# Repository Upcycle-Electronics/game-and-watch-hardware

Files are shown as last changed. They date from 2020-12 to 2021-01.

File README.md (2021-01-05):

# game-and-watch-hardware
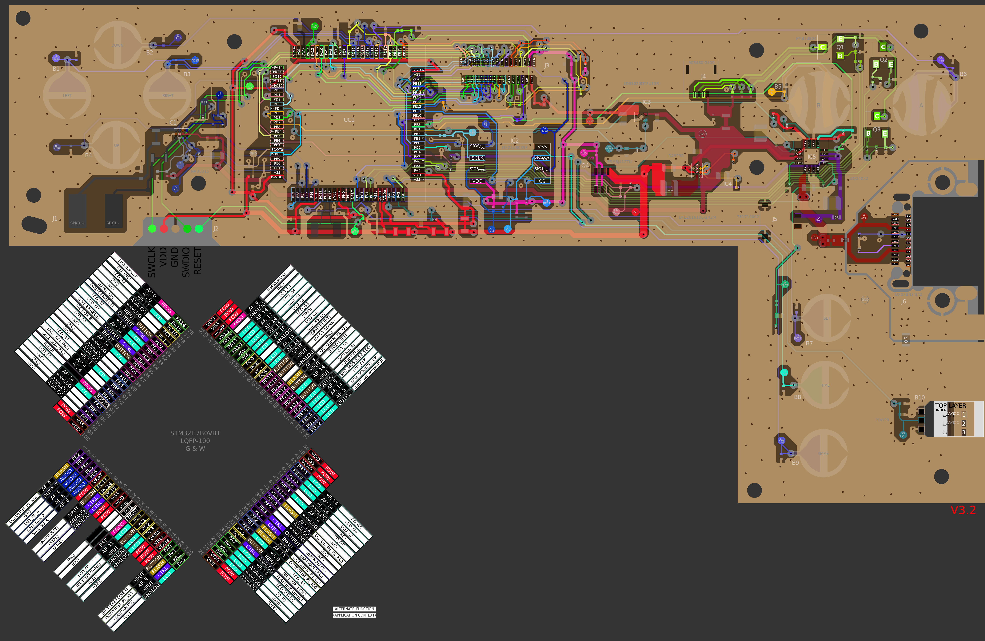
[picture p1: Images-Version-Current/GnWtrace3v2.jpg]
Version 3.2


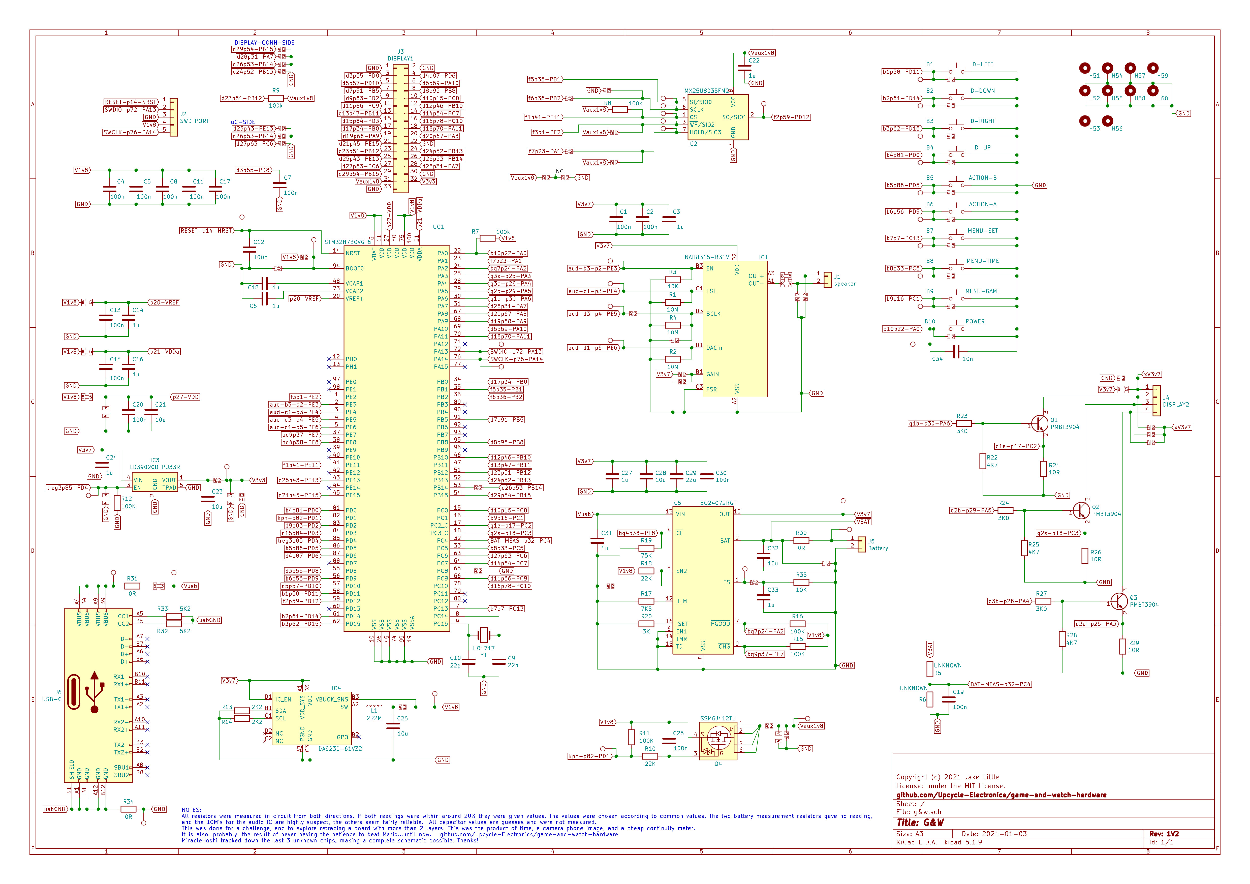
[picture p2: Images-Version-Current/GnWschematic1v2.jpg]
Version 1.2


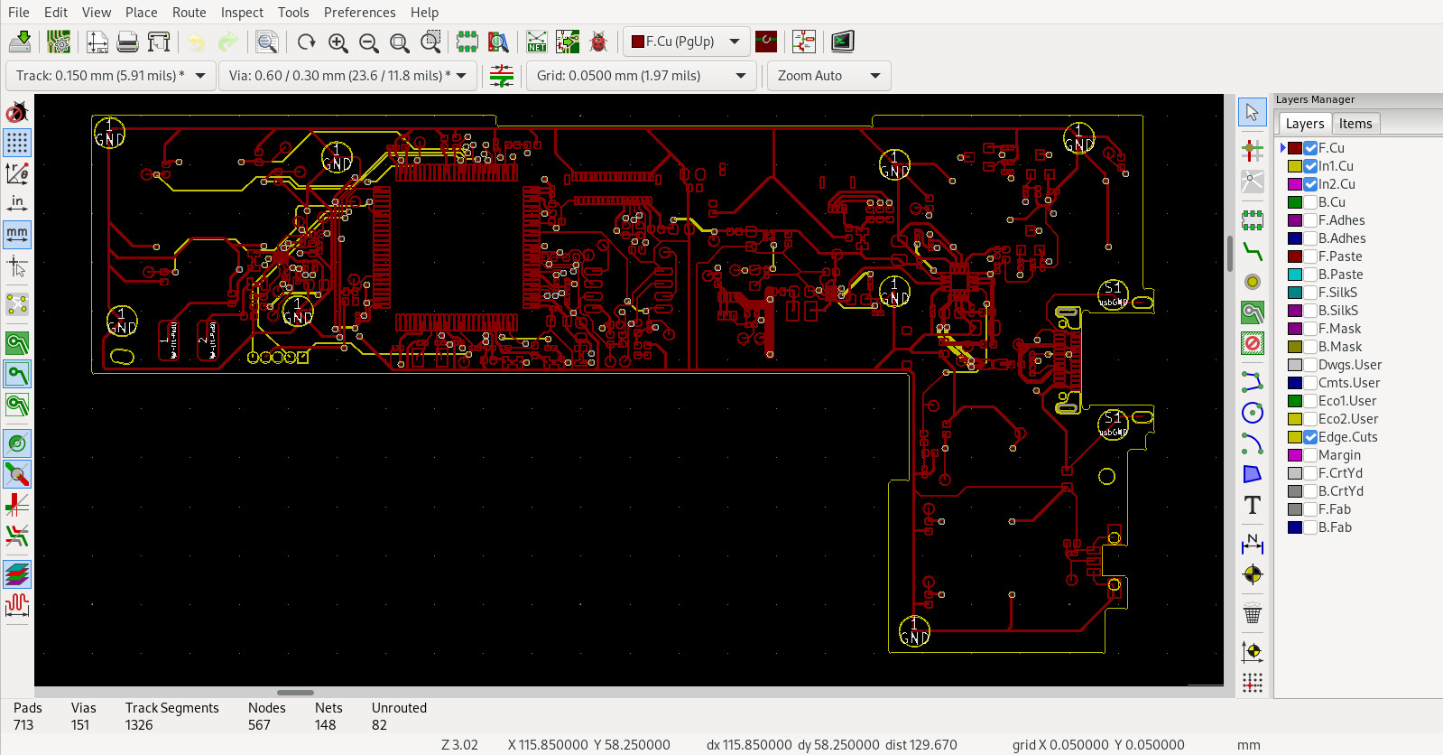
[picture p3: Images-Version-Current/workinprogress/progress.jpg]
progress


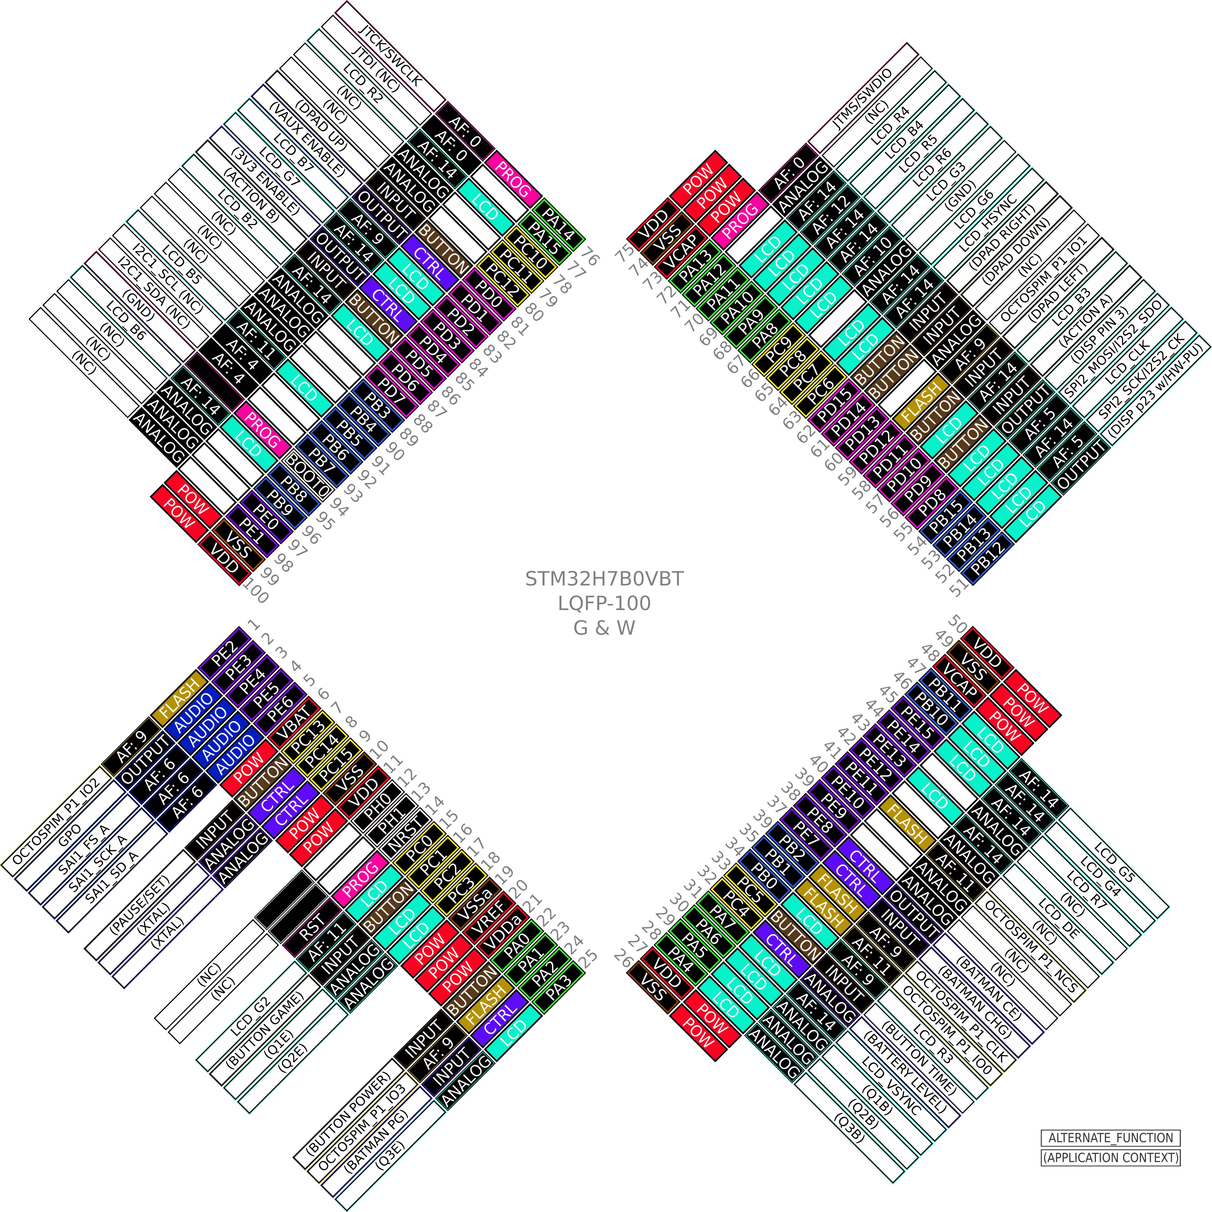
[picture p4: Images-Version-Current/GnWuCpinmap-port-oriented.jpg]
PinMap


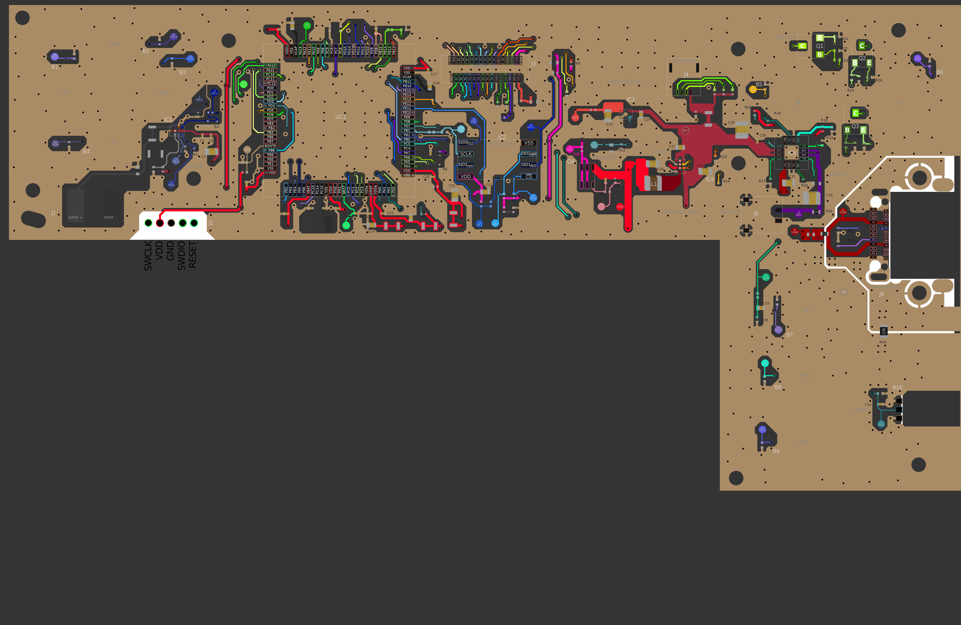
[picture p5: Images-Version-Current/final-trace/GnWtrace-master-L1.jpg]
Layer 1


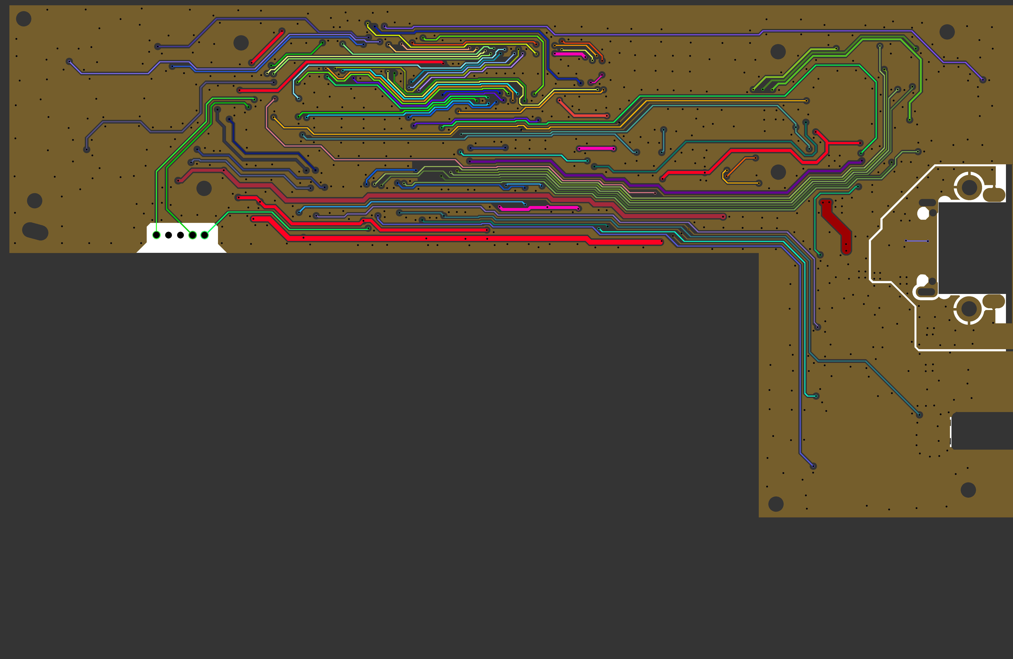
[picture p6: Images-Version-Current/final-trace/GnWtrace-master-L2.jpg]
Layer 2


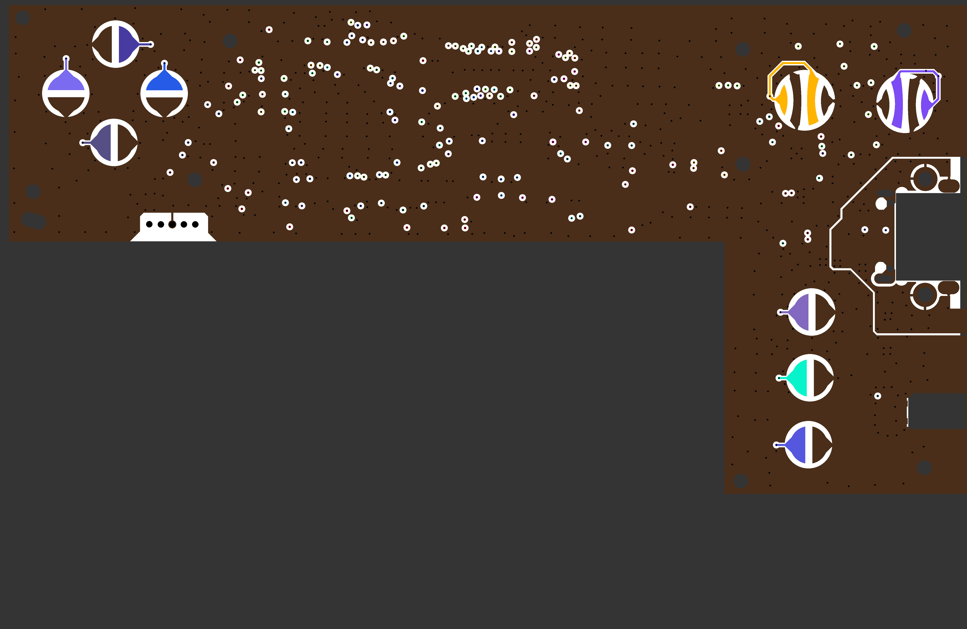
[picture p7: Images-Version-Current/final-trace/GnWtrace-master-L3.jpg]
Layer 3


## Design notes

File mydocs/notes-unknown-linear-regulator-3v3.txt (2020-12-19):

3V3 REGULATOR
IS NOT:
XC6220           no footprint match
XC6221           no footprint match
XC6222           no footprint match
XC6223           device marks do not match
XC6224           no footprint match
XC6225           no footprint match
XC6229           no footprint match
TLV707335DQN     device marks do not match F6
TLV70733DQNR     device marks do not match YH
TLV70733DQNR1    device marks do not match BN
TLV70733DQNT     device marks do not match YH
TLV70733PDQN     device marks do not match TI
TLV71733PDQN     device marks do not match VG
TLV73333PDQN     device marks do not match FM
TLV74233PDQN     device marks do not match 7Z
TLV75533PDQN     device marks do not match AN
LP5907SNX-3.3    device marks do not match CN
TPS7A0533PDQN    device marks do not match CD
TPS7A0333DQN     device marks do not match IH
TPS7A0333PDQN    device marks do not match G5
TPS7A0233DQN     device marks do not match IF
TPS7A0233PDQN    device marks do not match FA
LD6805K33P       device marks do not match 
RP202K           device marks may match but Ricoh does not spec marking or guarantee consistency

IS:
SIZE:
1mm x 1mm

FOOTPRINT COULD BE:
X2SON-4 1X1mm
DFN1010C-4
SOT1194-1
4-UDFN Exposed Pad
USPQ-4B03

PINOUT:
PIN 1 = output
PIN 2 = ground
PIN 3 = enable (active high)
PIN 4 = input

PARTNUMBER= maybe top line "M33" (M is underlined) ; is probably either "OH" or "0H" from the second line

----------------------------------------------------------------------------
DC TO DC CONVERTER:
IS: 
SIZE:
1.3mm x 1.8mm

FOOTPRINT COULD BE:
DSBGA-12

IS NOT:
listed on the TI website matching this package and marking codes
TPS62350YZGR device marks do not match TPS62350
TPS62352YZGR device marks do not match TPS62352
TPS62353YZG_ device marks do not match TPS62353
TPS62354YZGR device marks do not match TPS62354
TPS62356YZG_ device marks do not match TPS62356
 device marks do not match 
 device marks do not match 
 
MP28160 wrong size/wrong connections
BD83070 wrong size/wrong connections
MP5461 wrong size/wrong connections
MAX77503 wrong size/wrong connections

Almost Matching 12 ball footprints to ignore:
CSP-12      1.4mm x 1.8mm
UCSP50L1C   1.20mm × 1.60mm
W121A1+3    1.398mm +/-0.0025 x 1.848mm +/-0.0025

A=1 B=2 C=3
1A

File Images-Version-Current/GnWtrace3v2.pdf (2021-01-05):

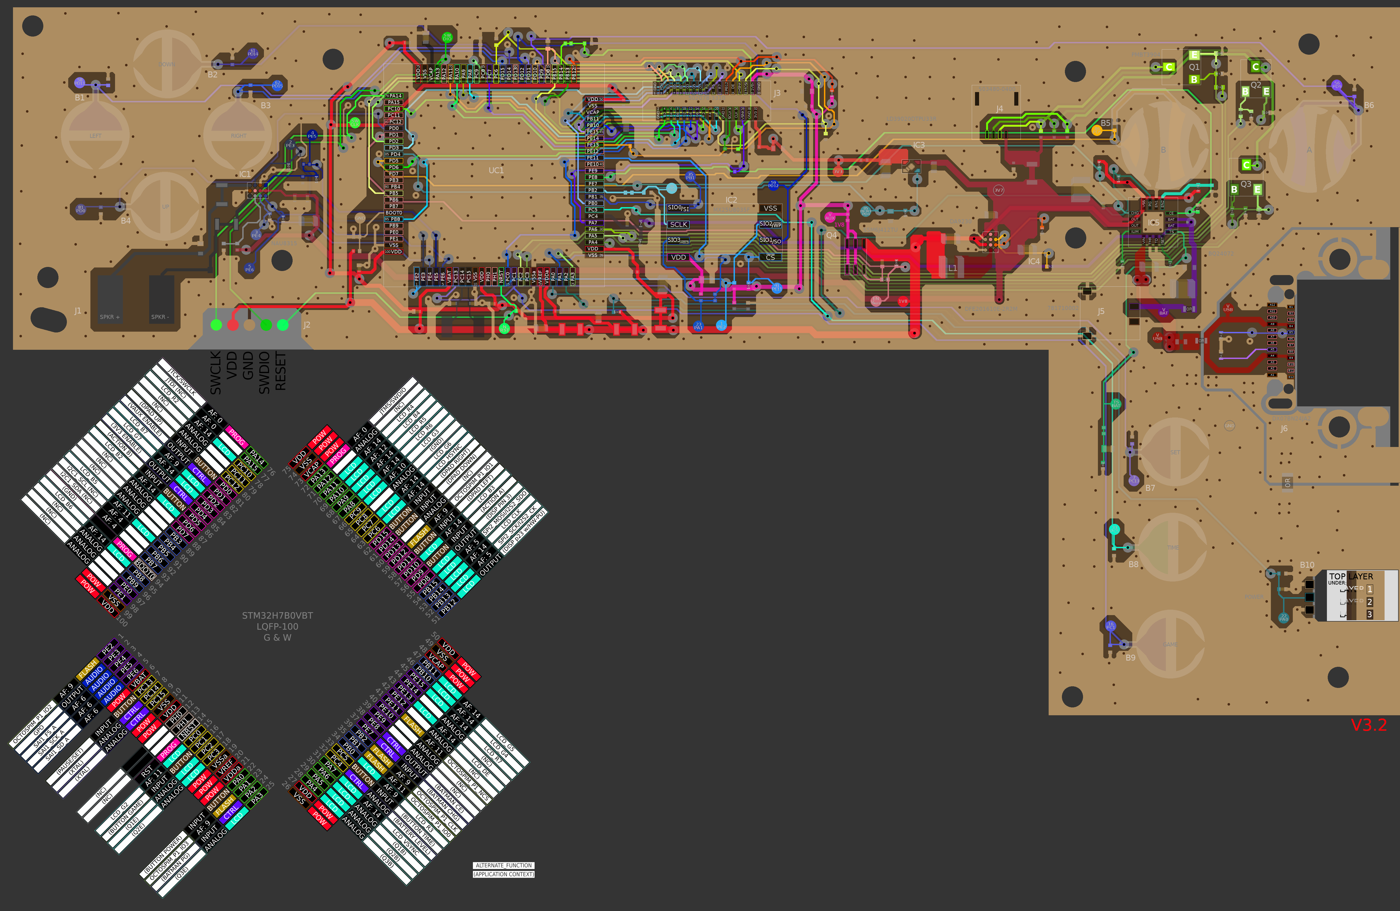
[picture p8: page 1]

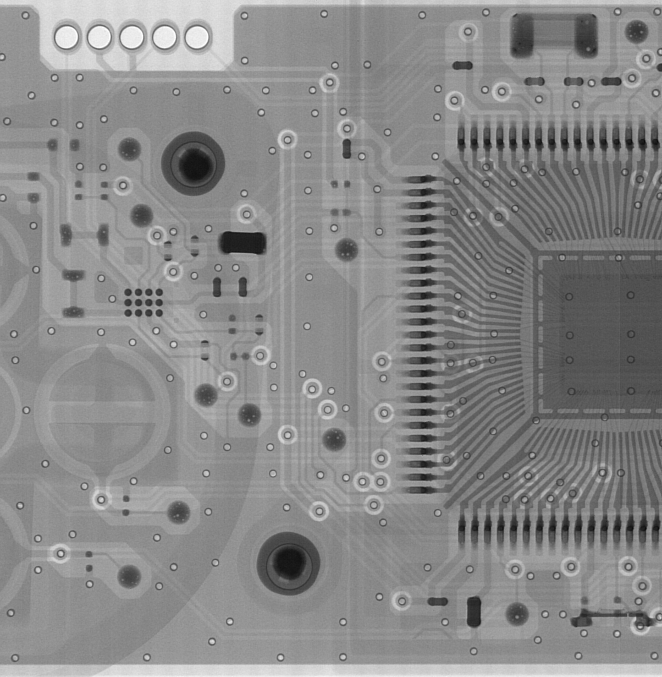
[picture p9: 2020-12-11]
gimp/board-pics/G&W CPU.jpg

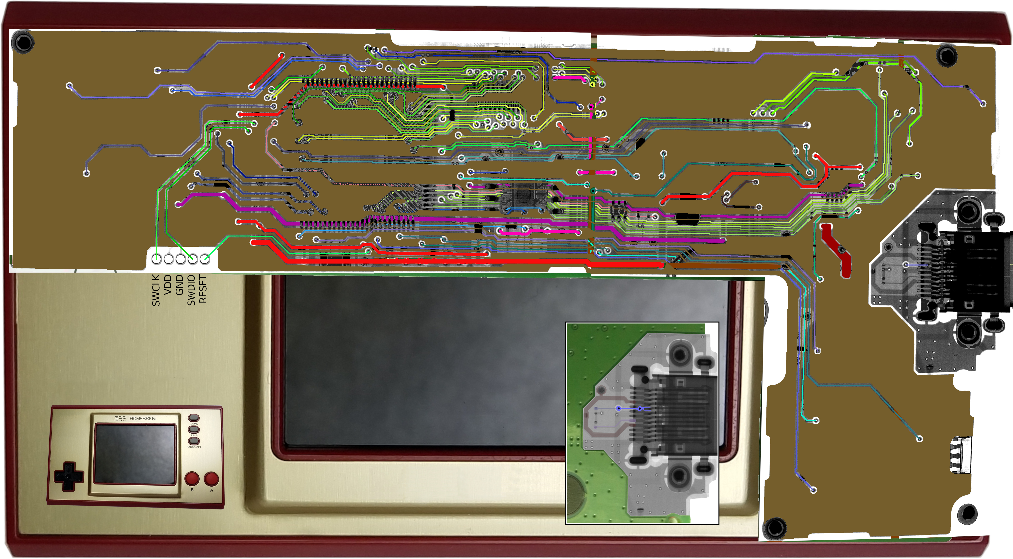
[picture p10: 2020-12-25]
gimp/board-pics/innerlayertraces.jpg

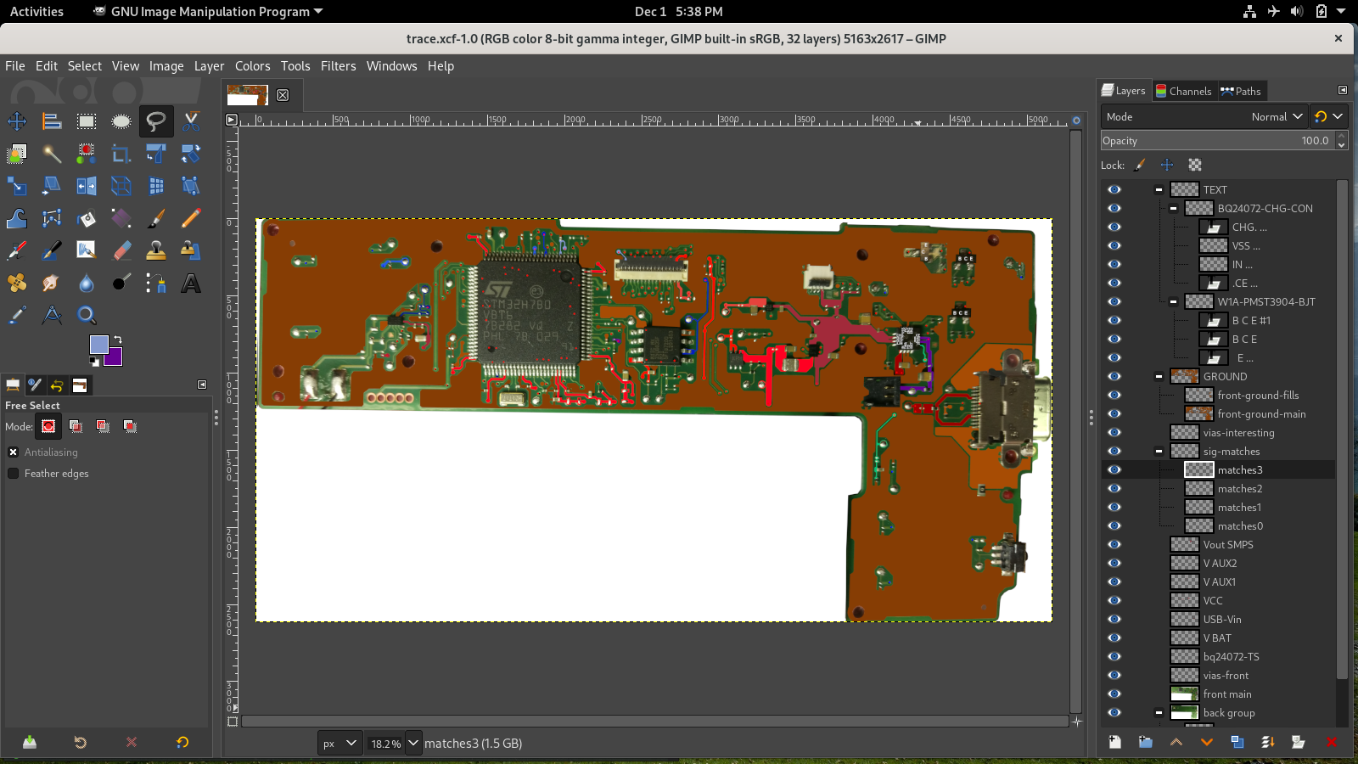
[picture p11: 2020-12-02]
gimp/board-pics/progress.png

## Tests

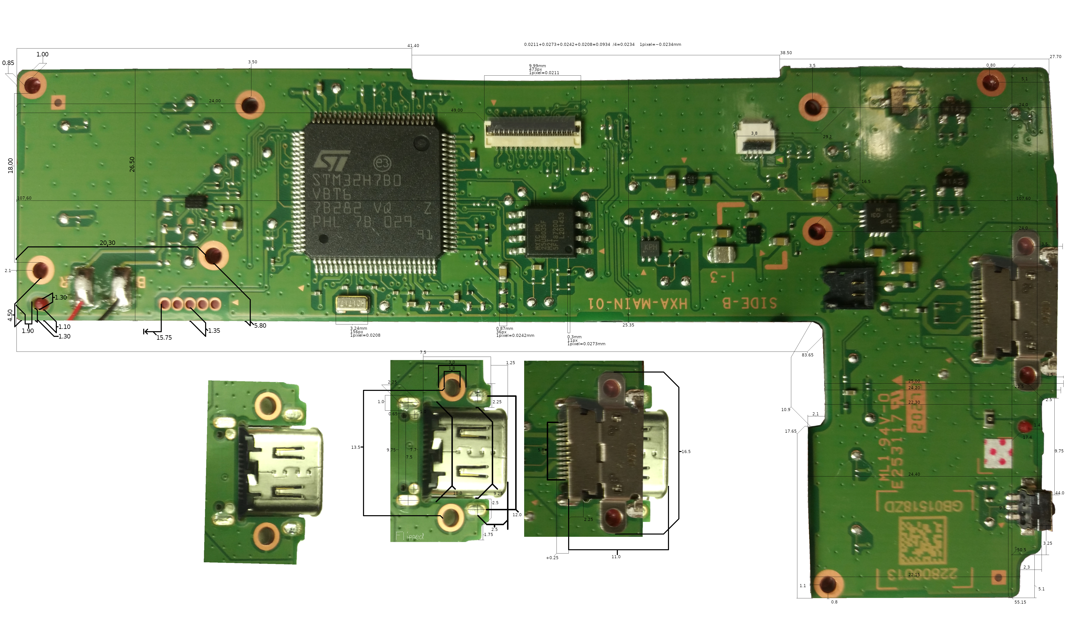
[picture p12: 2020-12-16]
Images-Version-Current/workinprogress/GnWtracemeasureWIP.jpg

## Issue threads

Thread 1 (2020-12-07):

Correction on regulator trace.

joksan, 2020-12-07:
Hello!

First of all, thank you for this amazing effort of reverse engineering the Game And Watch. It's been incredibly useful to me and I'm sure to others as well.

I just wanted to kindly point out an error I discovered in the colored trace images (GnWtrace1v0.png and others). In the 1.8V regulator area there's this SDM component that is an inductor in a 2016 package (it's right besides the M-1 label). Both ends of the inductor are colored the same, which suggests that they're joined together. I'm afraid those are different traces, as they show very different signals in an oscilloscope. This inductor is part of the buck converter circuit and has the output switch at the end that leads to the regulator IC and the actual power output going to the rest of the circuit at the other end.

I hope you find this little bit of information useful. Have a nice day!

Upcycle-Electronics, 2020-12-08:
I should have thought of that. Continuity isn't always continuity. I'll ty and push a change tomorrow.

  I guess this means that little stub of a trace on the left side of IC4 must be where the diode is hidden. Either that or I'm totally clueless about this switching topology. Both are equally possible. I really wish I could find out the chip used.
Thanks for letting me know.

Upcycle-Electronics, 2020-12-09:
I think I fixed it. Thanks again.
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

joksan, 2020-12-10:
Yay! thanks!

Closed 2020-12-09.

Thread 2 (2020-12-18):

I came to help.

miraclehoshi, 2020-12-18:
I noticed that you are not yet in Discord dealing with game and watch hacks.

Except for the power switch parts, all parts were found with the help of me and several people.

Type-C Connector : JAE DX07BN24JA2R1300
1.9V Reg : dialog semiconductor DA9230
3.3V Reg : STMicroelectronics LD39020DTPU33R
Audio Amplifier : nuvoton NAU8315

If you are interested, how about joining Discord?
https://discord.gg/P7uPM3Sy

Upcycle-Electronics, 2020-12-18:
Alright. I'll set up an account when I get back on a computer tomorrow. Thanks for the info.
Do you know the power button and crystal part number?
  Also, sources?
I searched:
smdmark.com (where I got the MOSFET pn from)
smd.yooneed.one
alltransistor.com
octopart
digikey, mouser, arrow, newark, ti, torex, lcsc, aliex
...so far. It seems you have sources and techniques I'd like to know and get familiar with.

miraclehoshi, 2020-12-18:
Crystal is a common standard, so I couldn't think of finding it. Let's try.
The sources of other parts were found by searching several sites. I was able to find it with various help.
I only used digikey and mouser.

The power switch part has been around for a long time on Nintendo, but I haven't been able to find the exact part yet. Considering that the genuine switch has not been found while at least three replica parts have been released in China, it may be a special ordered part from Nintendo.

Upcycle-Electronics, 2020-12-19:
Thanks for the help and info. Discord is not a good fit for me. Tracking down everything they are doing in the background is too much of a side project for a dumb guy like myself. Let me know if you guys move to something open source and privacy aware. I prefer a written messaging system anyways

  I wish the DA9230 wasn't made of unobtainium. That was the most interesting chip in the whole device. At least the pull down resistors to disable the I2C lines finally make sense.
If you read the documentation for the 9230 demo board they list a Murata inductor that is probably the one used on the GnW. At least it's the right odd footprint.

Upcycle-Electronics, 2020-12-20:
Thanks again. The schematic has been updated.

Closed 2020-12-20.

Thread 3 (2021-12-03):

STM32H7B0V(B|G?)T6

martaaay, 2021-12-03:
My apologies - I'm not familiar with the ST2 line, but I couldn't find STM32H7B0V**G**T6, but I did find STM32H7B0V**B**T6:
[linky](https://www.st.com/content/st_com/en/products/microcontrollers-microprocessors/stm32-32-bit-arm-cortex-mcus/stm32-high-performance-mcus/stm32h7-series/stm32h7b0-valu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
)
Just wondering if this is a typo.

Upcycle-Electronics, 2021-12-04:
Indeed it is a typo. QWERTY strikes again. I'm not fixing it ATM though. I'm too far removed from this project to sort it out and edit for a typo. I'm 4 months into buring out on my first large 3d printing project worth sharing and doing post design documentation. My brain is 180 degrees away from KiCAD right now. Hopefully my error didn't cost you too mach wasted time.
https://github.com/Upcycle-Electronics/game-and-watch-hardware/blob/main/gimp/board-pics/front1.jpg

martaaay, 2021-12-30:
Noooo worries. No time lost!

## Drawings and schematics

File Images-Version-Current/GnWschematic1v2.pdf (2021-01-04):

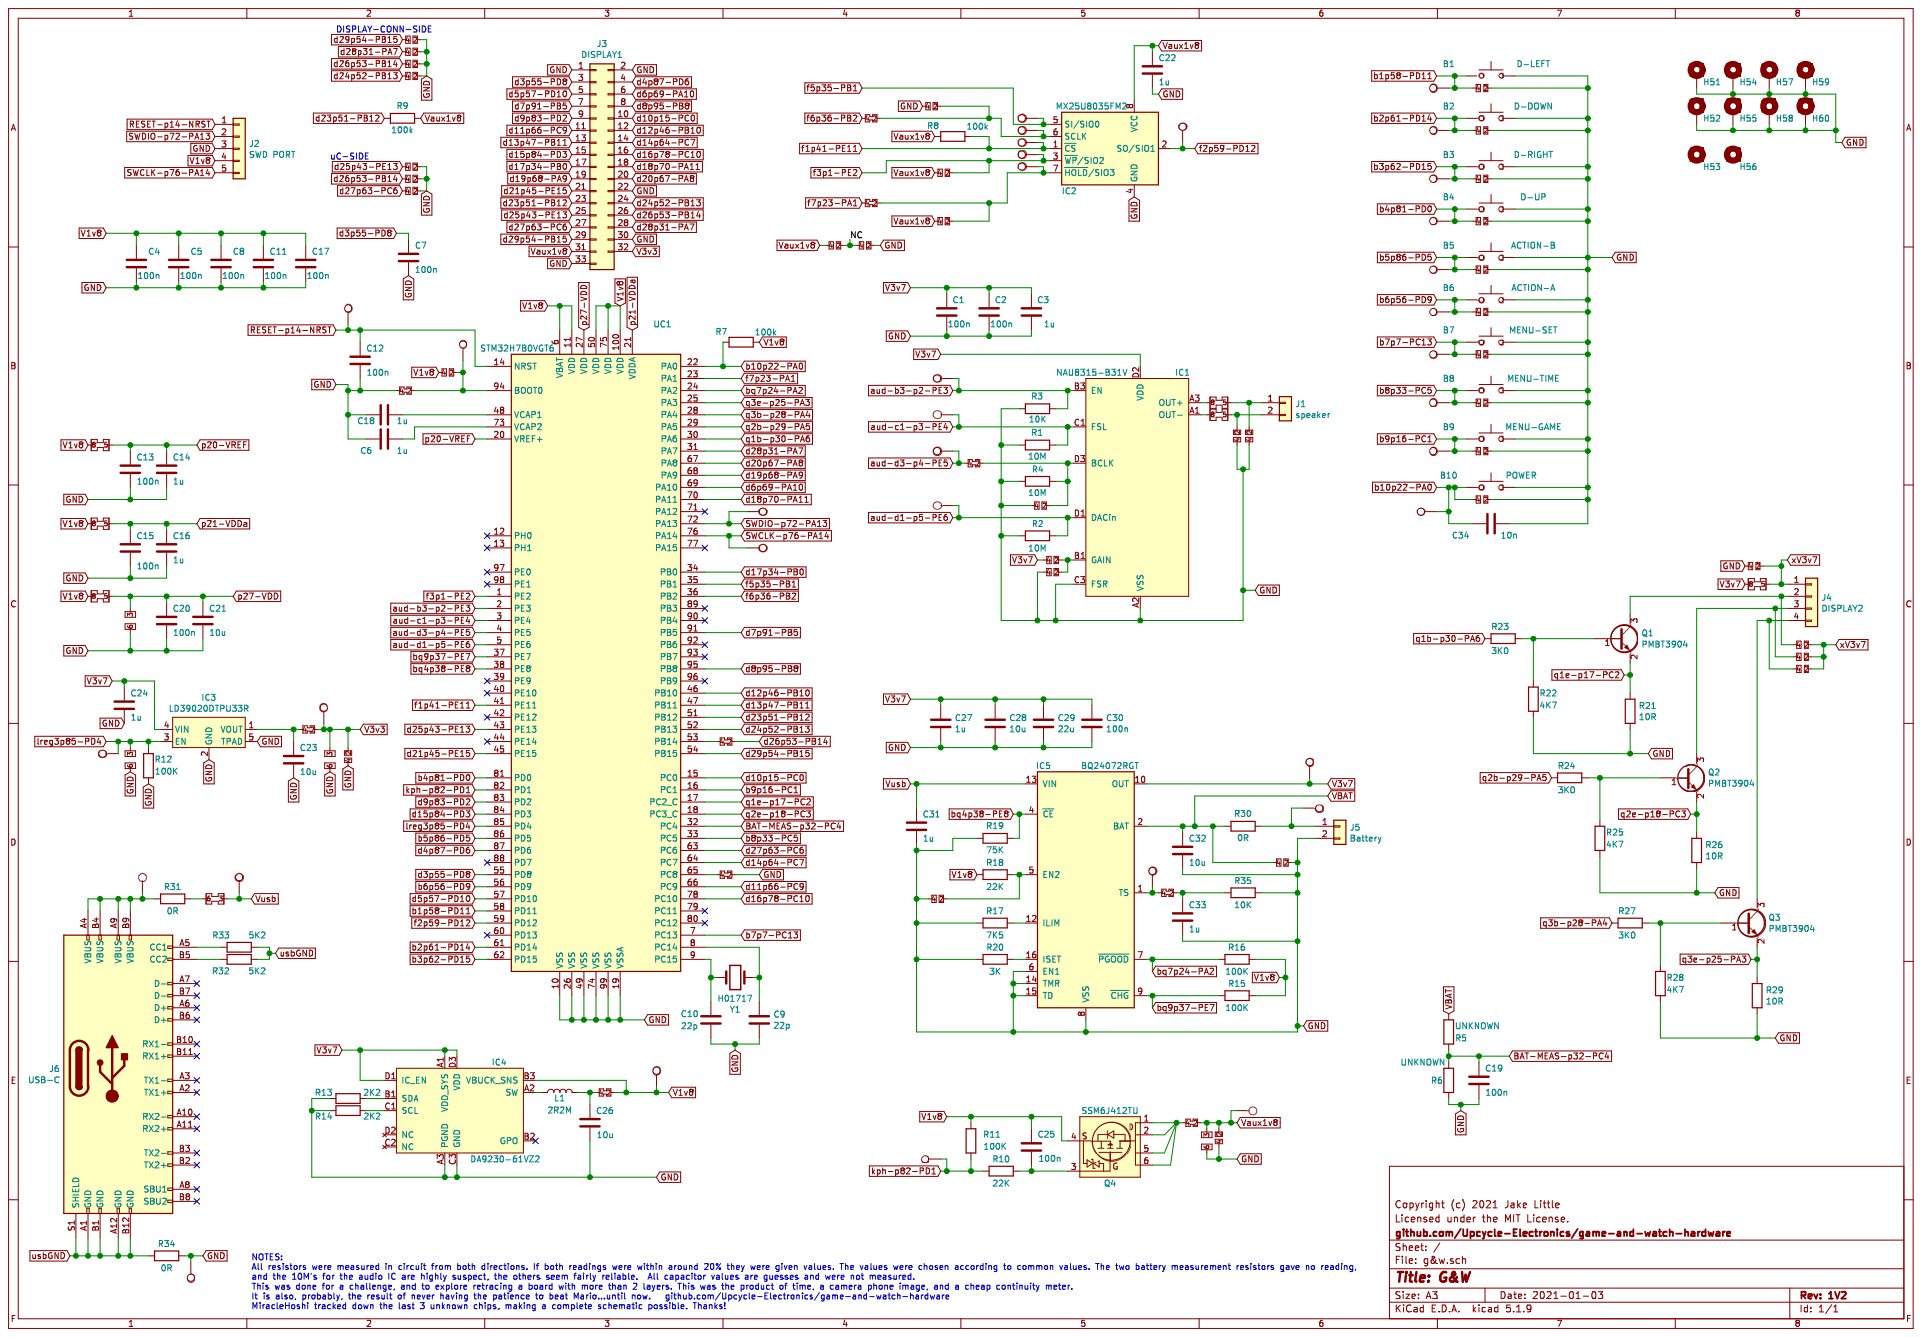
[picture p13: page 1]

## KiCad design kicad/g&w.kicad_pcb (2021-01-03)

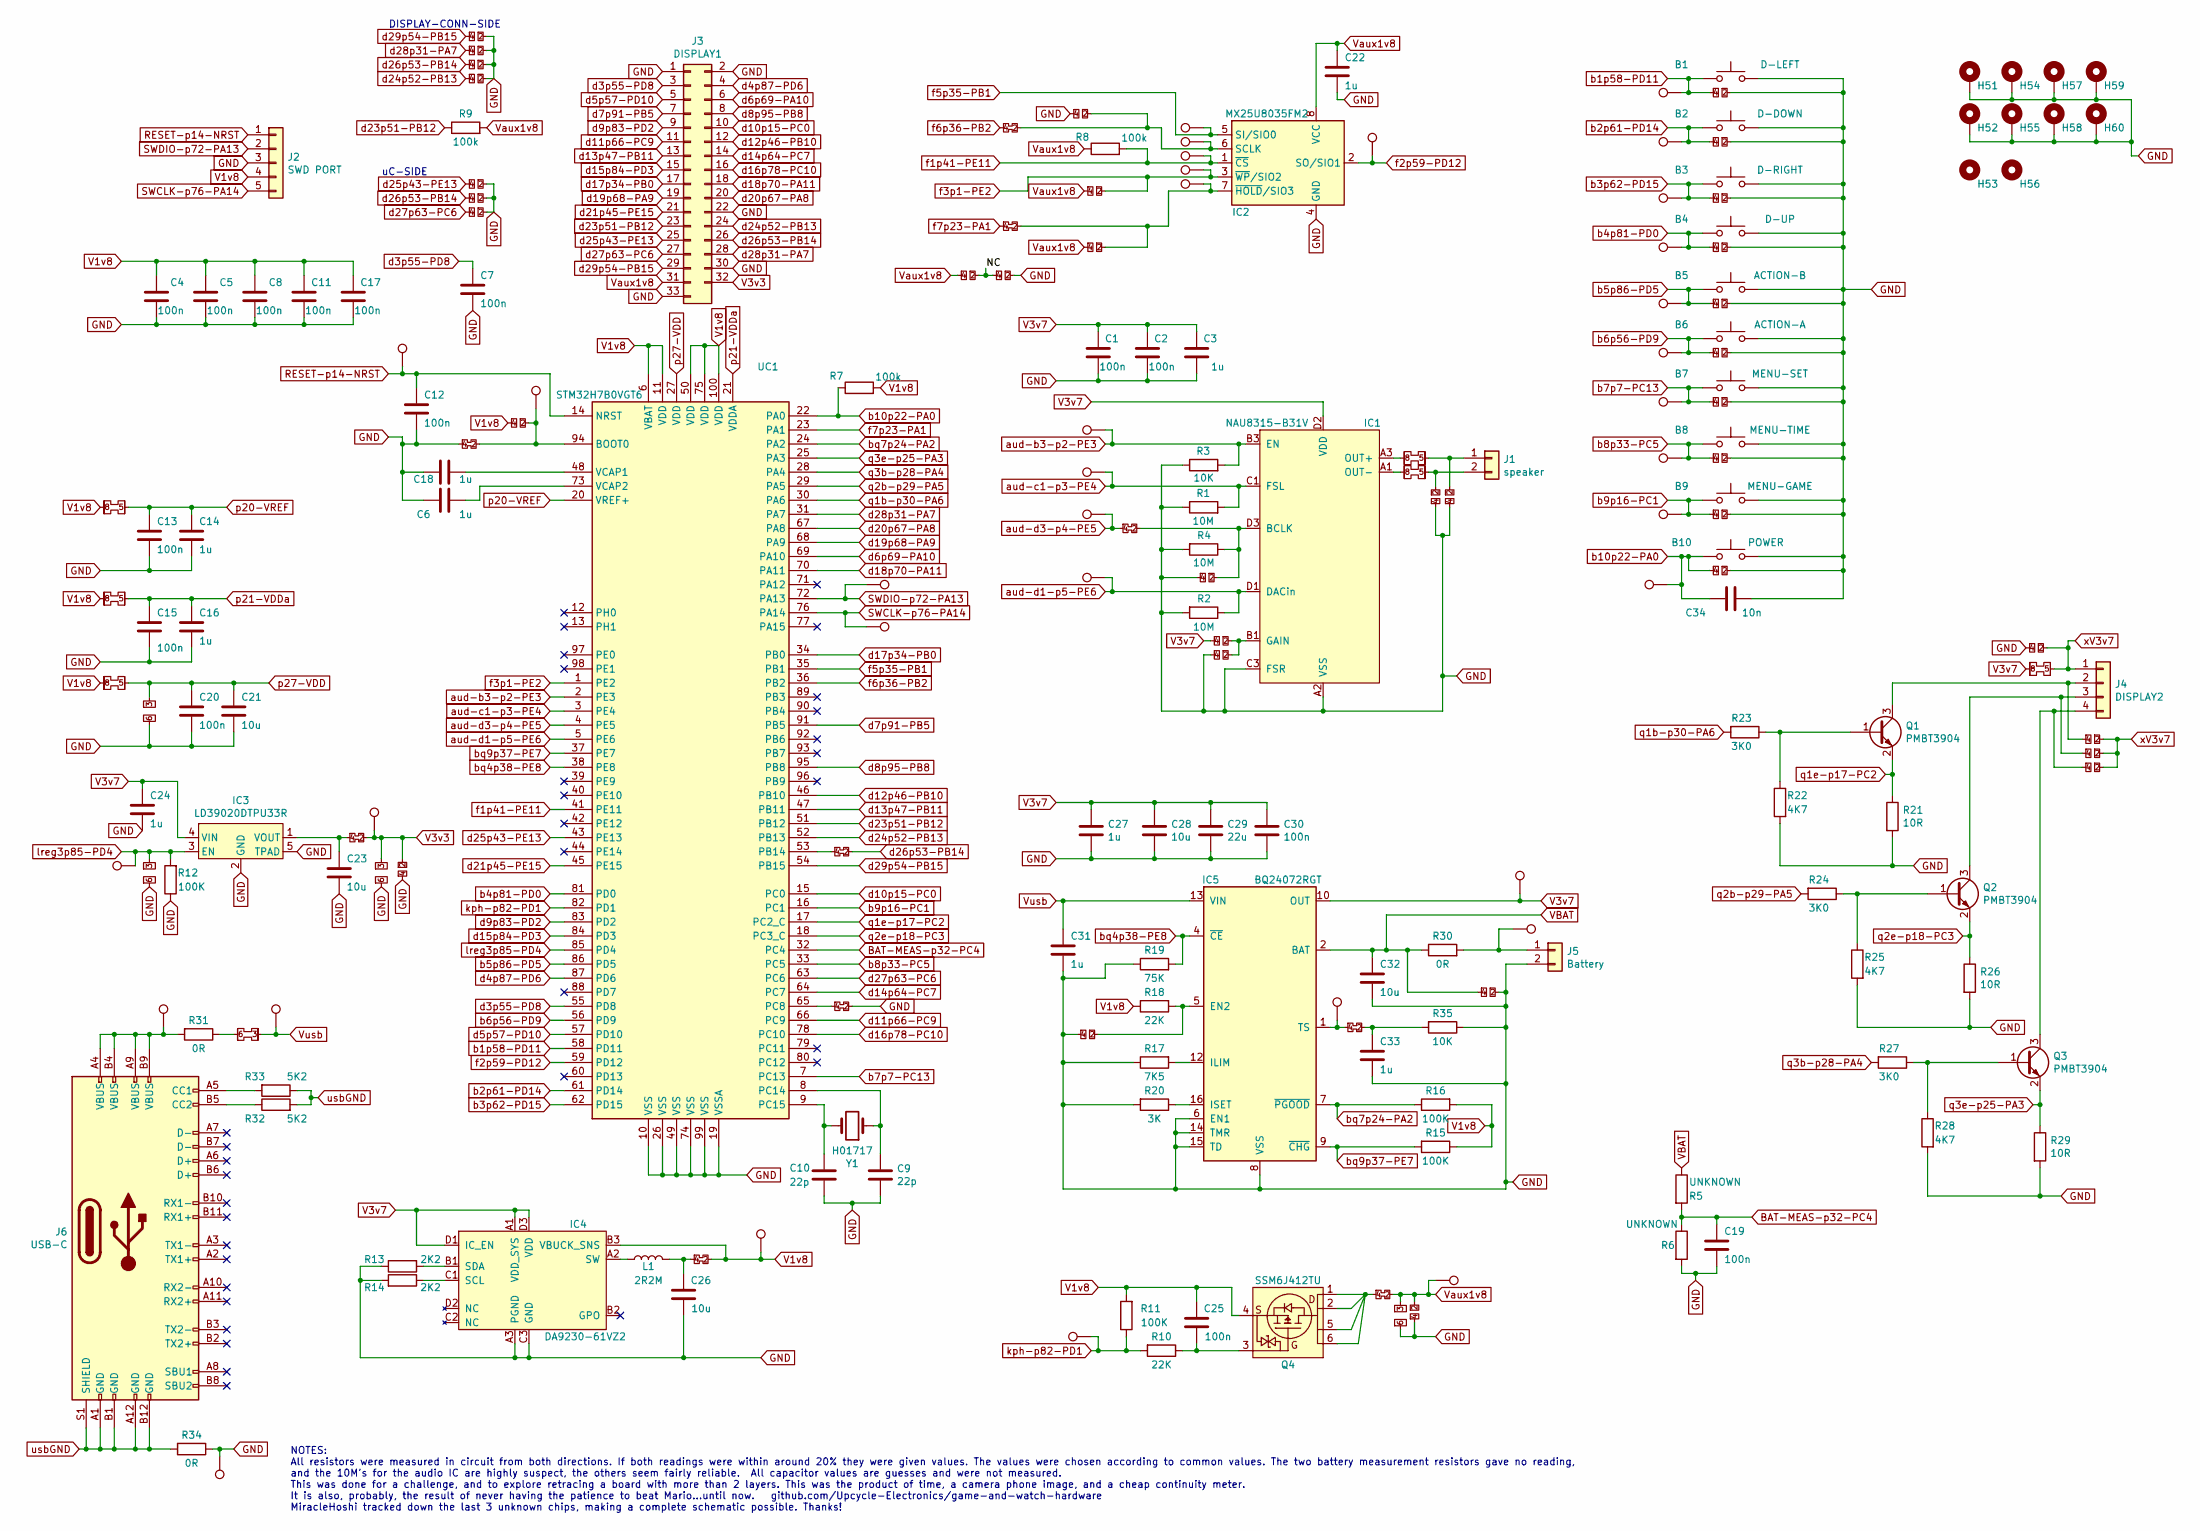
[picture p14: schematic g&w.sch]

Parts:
B1: D-LEFT; Button_Carbon-Contact_Round_5.00mm
B2: D-DOWN; Button_Carbon-Contact_Round_5.00mm
B3: D-RIGHT; Button_Carbon-Contact_Round_5.00mm
B4: D-UP; Button_Carbon-Contact_Round_5.00mm
B5: ACTION-B; Button_Carbon-Contact_Round_6.5mm
B6: ACTION-A; Button_Carbon-Contact_Round_6.5mm
B7: MENU-SET; Button_Carbon-Contact_Round_5.00mm
B8: MENU-TIME; Button_Carbon-Contact_Round_5.00mm
B9: MENU-GAME; Button_Carbon-Contact_Round_5.00mm
B10: POWER; SW_PUSH_1P1T_Horizontal_Nintendo_GnW
C1, C2, C4, C5, C7, C8, C11, C12, C13, C15, C17, C19, C20, C25, C30: 100n; C_0201_0603Metric
C3, C31: 1u; C_0603_1608Metric
C6, C14, C16, C18, C22, C24, C27, C33: 1u; C_0402_1005Metric
C9, C10: 22p; C_0201_0603Metric
C21, C23, C26, C28: 10u; C_0603_1608Metric
C29: 22u; C_0805_2012Metric
C32: 10u; C_0805_2012Metric
C34: 10n; C_0201_0603Metric
H51, H52, H54, H55, H57, H58, H59, H60: MountingHole_Pad; MountingHole_2.0mm
H53: MountingHole; MountingSlot_NC_1.3x2.2mm
H56: MountingHole; MountingHole_NC_1.5mm
IC1: NAU8315-B31V; WLCSP-12_1.18x1.95_Layout3x4_P0.4mm
IC2: MX25U8035FM2; SOP-8_5.28x5.23mm_P1.27mm
IC3: LD39020DTPU33R; DFN-4-1EP_1x1_P0.65mm_EP0.56x0.56mm
IC4: DA9230-61VZ2; WLCSP-12_1.28x1.68_Layout3x4_P0.4mm
IC5: BQ24072RGT; VQFN-16-1EP_3x3mm_P0.5mm_EP1.6x1.6mm
J1: speaker; Speaker
J2: SWD PORT; PinHeader_1x05_P1.27mm_Vertical
J3: DISPLAY1; Molex_502078-3310_2Rows-33Pins-1MP_P0.5mm-int0.25mm_Horizon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
J4: DISPLAY2; Molex_Easy-On_503480-0400_1x04-1MP_P1.00mm_Horizontal
J5: Battery; Molex_Pico-EZmate_78171-0002_1x02-1MP_P1.20mm_Vertical
J6: USB-C; USB_C_Receptacle_JAE_DX07BN24JA2
JP51, JP52, JP53, JP83, JP84, JP102: jmp-0805; JMP-0805-CLOSED
JP54, JP55, JP58, JP89: JMP-0603-OPEN; R_0603_1608Metric
JP56: JMP-0603-CLOSED
JP57, JP67, JP69, JP70, JP72, JP73, JP77, JP82, JP85, JP88: JMP-0402-CLOSED
JP59, JP60, JP61, JP62, JP63, JP64, JP65, JP66, JP68, JP71, JP74, JP75, JP76, JP78, JP79, JP80, JP81, JP86, JP87, JP90, JP91, JP92, JP93, JP94, JP95, JP96, JP97, JP98, JP99, JP100, JP101, JP103, JP104, JP105, JP106, JP107: JMP-0402-OPEN; R_0402_1005Metric
L1: 2R2M; L_0806_2016Metric
Q1, Q2, Q3: PMBT3904; SOT-23
Q4: SSM6J412TU; Toshiba_UF6_SOT363F
R1, R2, R4: 10M; R_0201_0603Metric
R3, R35: 10K; R_0201_0603Metric
R5, R6: UNKNOWN; R_0201_0603Metric
R7, R8, R9: 100k; R_0201_0603Metric
R10, R18: 22K; R_0201_0603Metric
R11, R12, R15, R16: 100K; R_0201_0603Metric
R13, R14: 2K2; R_0201_0603Metric
R17: 7K5; R_0201_0603Metric
R19: 75K; R_0201_0603Metric
R20: 3K; R_0201_0603Metric
R21, R26, R29: 10R; R_0201_0603Metric
R22, R25, R28: 4K7; R_0201_0603Metric
R23, R24, R27: 3K0; R_0201_0603Metric
R30, R31: 0R; R_0402_1005Metric
R32, R33: 5K2; R_0201_0603Metric
R34: 0R; R_0603_1608Metric
TP51, TP52, TP53, TP54, TP55, TP56, TP57, TP58, TP59, TP60, TP61, TP62, TP63, TP64, TP65, TP66, TP67, TP68, TP69, TP70, TP71, TP72, TP73, TP74, TP75, TP76, TP77, TP78, TP79, TP80, TP81, TP82, TP83, TP84, TP85: TestPoint; gnw-TestPoint_Pad_D1.0mm
UC1: STM32H7B0VGT6; LQFP-100_14x14mm_P0.5mm
Y1: H01717; Crystal_SMD_3215-2Pin_3.2x1.5mm

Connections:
/NC: JP106.2, JP107.1
BAT-MEAS-p32-PC4: C19.1, R5.2, R6.1, UC1.32 (PC4)
GND: B1.2, B2.2, B3.2, B4.2, B5.2, B6.2, B7.2, B8.2, B9.2, B10.1, C1.2, C2.2, C3.2, C4.2, C5.2, C6.1, C7.2, C8.2, C9.2, C10.2, C11.2, C12.2, C13.2, C14.2, C15.2, C16.2, C17.2, C18.2, C19.2, C20.2, C21.2, C22.2, C23.2, C24.2, C26.2, C27.2, C28.2, C29.2, C30.2, C31.2, C32.2, C33.2, C34.2, H51.1, H52.1, H54.1, H55.1, H57.1, H58.1, H59.1, H60.1, IC1.A2 (VSS), IC1.C3 (FSR), IC2.4 (GND), IC3.2 (GND), IC3.5 (TPAD), IC4.A3 (PGND), IC4.C3 (GND), IC5.6 (EN1), IC5.8 (VSS), IC5.14 (TMR), IC5.15 (TD), IC5.17 (VSS), J2.3, J3.1, J3.2, J3.22, J3.30, J3.33, J5.2, JP54.1, JP55.1, JP58.1, JP59.1, JP60.2, JP61.2, JP62.2, JP63.2, JP64.2, JP65.2, JP66.2, JP67.1, JP70.2, JP71.1, JP74.1, JP78.1, JP79.1, JP81.2, JP86.1, JP87.1, JP89.1, JP90.1, JP91.2, JP92.2, JP93.2, JP94.2, JP95.2, JP96.2, JP97.2, JP98.2, JP99.2, JP100.2, JP101.1, JP107.2, R1.1, R2.2, R3.1, R4.2, R6.2, R12.1, R13.1, R14.2, R17.1, R19.1, R20.2, R21.2, R22.2, R25.2, R26.2, R28.2, R29.2, R34.1, R35.1, TP53.1, UC1.10 (VSS), UC1.19 (VSSA), UC1.26 (VSS), UC1.49 (VSS), UC1.74 (VSS), UC1.99 (VSS)
unnamed: C6.2, UC1.73 (VCAP2)
unnamed: C9.1, UC1.8 (PC14), Y1.1
unnamed: C10.1, UC1.9 (PC15), Y1.2
unnamed: C18.1, UC1.48 (VCAP1)
unnamed: C23.1, IC3.1 (VOUT), JP57.1
unnamed: C25.1, Q4.3, R10.1
unnamed: C26.1, JP82.1, L1.2
unnamed: C33.1, JP88.2, R35.2
unnamed: IC1.A1 (OUT-), JP84.1
unnamed: IC1.A3 (OUT+), JP83.1
unnamed: IC1.B1 (GAIN), JP79.2, JP80.2
unnamed: IC1.D3 (BCLK), JP77.2, JP78.2, R4.1
unnamed: IC2.6 (SCLK), JP72.2, JP74.2, TP63.1
unnamed: IC2.7 (~HOLD~/SIO3), JP73.2, JP76.2, TP66.1
unnamed: IC4.A2 (SW), L1.1
unnamed: IC4.B1 (SDA), R13.2
unnamed: IC4.C1 (SCL), R14.1
unnamed: IC5.1 (TS), JP88.1, TP68.1
unnamed: IC5.5 (EN2), JP71.2, R18.2
unnamed: IC5.12 (ILIM), R17.2
unnamed: IC5.16 (ISET), R20.1
unnamed: J1.1, JP83.2, JP87.2
unnamed: J1.2, JP84.2, JP86.2
unnamed: J4.2, JP103.1, Q1.3 (C)
unnamed: J4.3, JP104.1, Q2.3 (C)
unnamed: J4.4, JP105.1, Q3.3 (C)
unnamed: J5.1, R30.2, TP70.1
unnamed: J6.A4 (VBUS), J6.A9 (VBUS), J6.B4 (VBUS), J6.B9 (VBUS), R31.2, TP52.1
unnamed: J6.A5 (CC1), R33.2
unnamed: J6.B5 (CC2), R32.1
unnamed: JP56.1, R31.1
unnamed: JP67.2, JP68.2, TP56.1, UC1.94 (BOOT0)
unnamed: JP69.1, UC1.53 (PB14)
unnamed: JP70.1, UC1.65 (PC8)
unnamed: JP85.1, Q4.1, Q4.2, Q4.5, Q4.6
unnamed: Q1.1 (B), R22.1, R23.1
unnamed: Q2.1 (B), R24.1, R25.1
unnamed: Q3.1 (B), R27.1, R28.1
RESET-p14-NRST: C12.1, J2.1, TP81.1, UC1.14 (NRST)
SWCLK-p76-PA14: J2.5, TP83.1, UC1.76 (PA14)
SWDIO-p72-PA13: J2.2, TP82.1, UC1.72 (PA13)
V1v8: C4.1, C5.1, C8.1, C11.1, C17.1, C25.2, IC4.B3 (VBUCK_SNS), J2.4, JP51.1, JP52.1, JP53.1, JP68.1, JP82.2, Q4.4, R7.2, R11.2, R15.1, R16.2, R18.1, TP84.1, UC1.6 (VBAT), UC1.11 (VDD), UC1.50 (VDD), UC1.75 (VDD), UC1.100 (VDD)
V3v3: J3.32, JP57.2, JP58.2, JP59.2, TP55.1
V3v7: C1.1, C2.1, C3.1, C24.1, C27.1, C28.1, C29.1, C30.1, IC1.B2 (VDD), IC1.C2 (VDD), IC1.D2 (VDD), IC3.4 (VIN), IC4.A1 (VDD_SYS), IC4.D1 (IC_EN), IC4.D3 (VDD), IC5.10 (OUT), IC5.11 (OUT), JP80.1, JP102.1, TP85.1
VBAT: C32.1, IC5.2 (BAT), IC5.3 (BAT), JP81.1, R5.1, R30.1
Vaux1v8: C22.1, IC2.8 (VCC), J3.31, JP75.1, JP76.1, JP85.2, JP89.2, JP90.2, JP106.1, R8.1, R9.2, TP69.1
Vusb: C31.1, IC5.13 (VIN), JP56.2, TP54.1
aud-b3-p2-PE3: IC1.B3 (EN), R3.2, TP60.1, UC1.2 (PE3)
aud-c1-p3-PE4: IC1.C1 (FSL), R1.2, TP58.1, UC1.3 (PE4)
aud-d1-p5-PE6: IC1.D1 (DACin), R2.1, TP57.1, UC1.5 (PE6)
aud-d3-p4-PE5: JP77.1, TP59.1, UC1.4 (PE5)
b1p58-PD11: B1.1, JP91.1, TP72.1, UC1.58 (PD11)
b2p61-PD14: B2.1, JP92.1, TP73.1, UC1.61 (PD14)
b3p62-PD15: B3.1, JP93.1, TP74.1, UC1.62 (PD15)
b4p81-PD0: B4.1, JP94.1, TP75.1, UC1.81 (PD0)
b5p86-PD5: B5.1, JP95.1, TP76.1, UC1.86 (PD5)
b6p56-PD9: B6.1, JP96.1, TP77.1, UC1.56 (PD9)
b7p7-PC13: B7.1, JP97.1, TP78.1, UC1.7 (PC13)
b8p33-PC5: B8.1, JP98.1, TP79.1, UC1.33 (PC5)
b9p16-PC1: B9.1, JP99.1, TP80.1, UC1.16 (PC1)
b10p22-PA0: B10.2, C34.1, JP100.1, R7.1, TP71.1, UC1.22 (PA0)
bq4p38-PE8: IC5.4 (~CE), R19.2, UC1.38 (PE8)
bq7p24-PA2: IC5.7 (~PGOOD), R16.1, UC1.24 (PA2)
bq9p37-PE7: IC5.9 (~CHG), R15.2, UC1.37 (PE7)
d3p55-PD8: C7.1, J3.3, UC1.55 (PD8)
d4p87-PD6: J3.4, UC1.87 (PD6)
d5p57-PD10: J3.5, UC1.57 (PD10)
d6p69-PA10: J3.6, UC1.69 (PA10)
d7p91-PB5: J3.7, UC1.91 (PB5)
d8p95-PB8: J3.8, UC1.95 (PB8)
d9p83-PD2: J3.9, UC1.83 (PD2)
d10p15-PC0: J3.10, UC1.15 (PC0)
d11p66-PC9: J3.11, UC1.66 (PC9)
d12p46-PB10: J3.12, UC1.46 (PB10)
d13p47-PB11: J3.13, UC1.47 (PB11)
d14p64-PC7: J3.14, UC1.64 (PC7)
d15p84-PD3: J3.15, UC1.84 (PD3)
d16p78-PC10: J3.16, UC1.78 (PC10)
d17p34-PB0: J3.17, UC1.34 (PB0)
d18p70-PA11: J3.18, UC1.70 (PA11)
d19p68-PA9: J3.19, UC1.68 (PA9)
d20p67-PA8: J3.20, UC1.67 (PA8)
d21p45-PE15: J3.21, UC1.45 (PE15)
d23p51-PB12: J3.23, R9.1, UC1.51 (PB12)
d24p52-PB13: J3.24, JP63.1, UC1.52 (PB13)
d25p43-PE13: J3.25, JP64.1, UC1.43 (PE13)
d26p53-PB14: J3.26, JP62.1, JP65.1, JP69.2
d27p63-PC6: J3.27, JP66.1, UC1.63 (PC6)
d28p31-PA7: J3.28, JP61.1, UC1.31 (PA7)
d29p54-PB15: J3.29, JP60.1, UC1.54 (PB15)
f1p41-PE11: IC2.1 (~CS), R8.2, TP64.1, UC1.41 (PE11)
f2p59-PD12: IC2.2 (SO/SIO1), TP67.1, UC1.59 (PD12)
f3p1-PE2: IC2.3 (~WP~/SIO2), JP75.2, TP65.1, UC1.1 (PE2)
f5p35-PB1: IC2.5 (SI/SIO0), TP62.1, UC1.35 (PB1)
f6p36-PB2: JP72.1, UC1.36 (PB2)
f7p23-PA1: JP73.1, UC1.23 (PA1)
kph-p82-PD1: R10.2, R11.1, TP61.1, UC1.82 (PD1)
lreg3p85-PD4: IC3.3 (EN), JP55.2, R12.2, TP51.1, UC1.85 (PD4)
p20-VREF: C13.1, C14.1, JP51.2, UC1.20 (VREF+)
p21-VDDa: C15.1, C16.1, JP52.2, UC1.21 (VDDA)
p27-VDD: C20.1, C21.1, JP53.2, JP54.2, UC1.27 (VDD)
q1b-p30-PA6: R23.2, UC1.30 (PA6)
q1e-p17-PC2: Q1.2 (E), R21.1, UC1.17 (PC2_C)
q2b-p29-PA5: R24.2, UC1.29 (PA5)
q2e-p18-PC3: Q2.2 (E), R26.1, UC1.18 (PC3_C)
q3b-p28-PA4: R27.2, UC1.28 (PA4)
q3e-p25-PA3: Q3.2 (E), R29.1, UC1.25 (PA3)
usbGND: J6.A1 (GND), J6.A12 (GND), J6.B1 (GND), J6.B12 (GND), J6.S1 (SHIELD), R32.2, R33.1, R34.2
xV3v7: J4.1, JP101.2, JP102.2, JP103.2, JP104.2, JP105.2

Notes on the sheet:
uC-SIDE
DISPLAY-CONN-SIDE
NOTES: All resistors were measured in circuit from both directions. If both readings were within around 20% they were given values. The values were chosen according to common values. The two battery measurement resistors gave no reading, and the 10M's for the audio IC are highly suspect, the others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

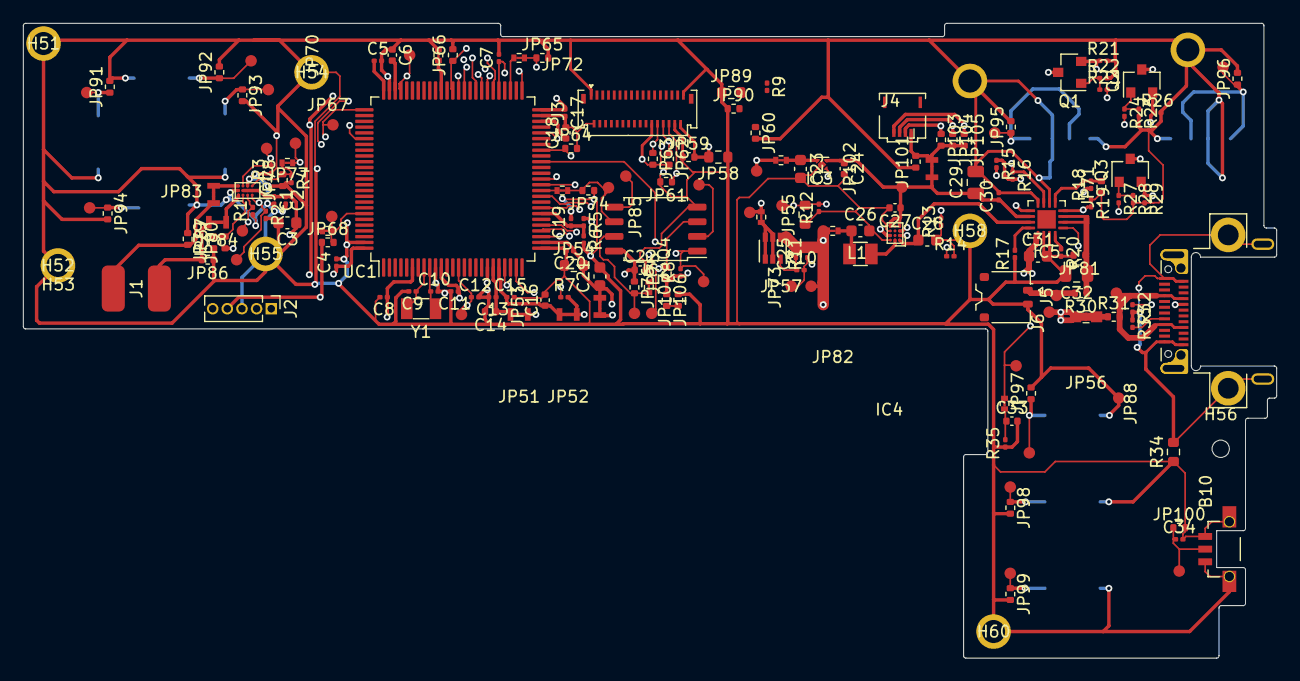
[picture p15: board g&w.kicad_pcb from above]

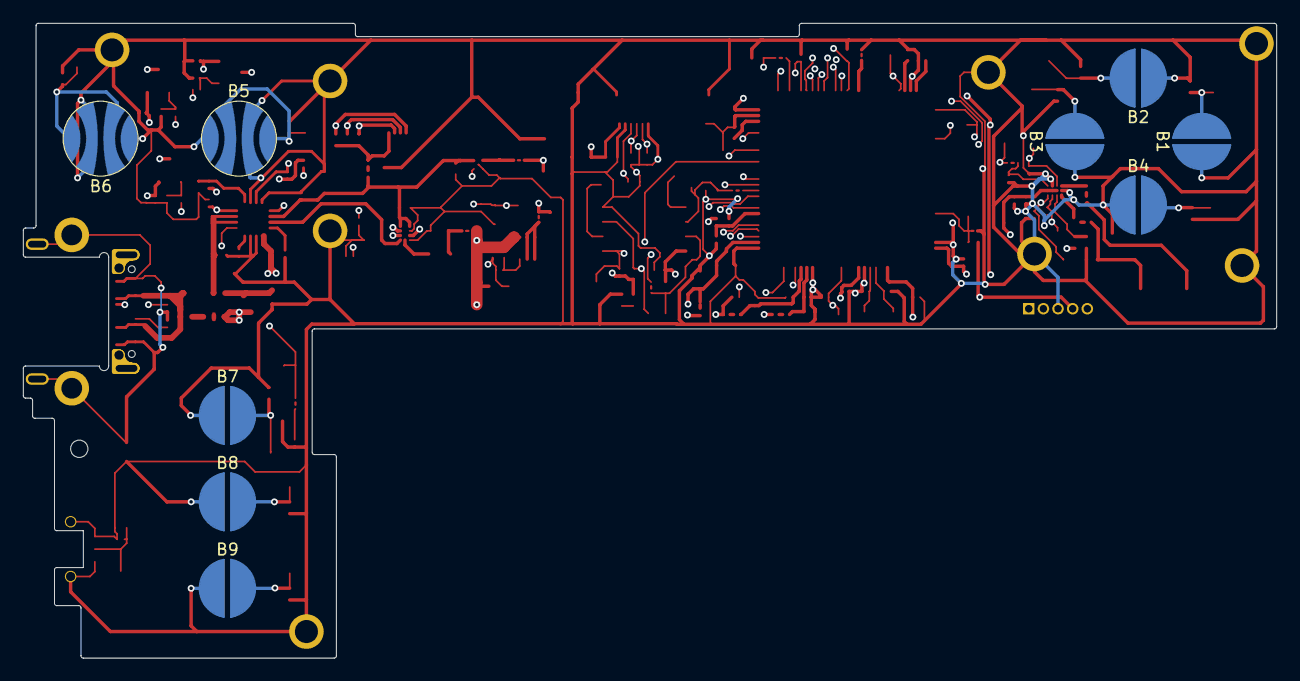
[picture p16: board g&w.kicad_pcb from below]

Board: 4 copper layers, 108.7 x 55.1 mm, 199 parts (9 on the bottom side), 112 nets.

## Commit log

2020-12-05 xrays are fun
    [g&w.sch]
2020-12-07 Retrace Version 1.0 and spreadsheet pin maps started
    [STM32H7B0-PinDescription-LQFP100.xlsx, g&w.sch]
2020-12-09 Version 1v11 fix USB pin connection
2020-12-10 schematic progress
    [g&w.sch]
2020-12-11 Version 1.12
    [STM32H7B0-PinDescription-LQFP100.xlsx, g&w.sch]
2020-12-12 Version 1.13/designators for R/C's and in-circuit R-meas-vals/kicad0v2
    [g&w.sch]
2020-12-13 4 footprints left to create b4 layout begins
    [g&w.sch]
2020-12-15 trace 1v14/Schematic 1v0/layout begins
    [g&w.kicad_pcb, g&w.sch]
2020-12-16 kicad board outline
    [g&w.kicad_pcb, g&w.sch]
2020-12-17 tweak footprints, setup design rules for 4 layers at common proto board house and refine board outline
    [g&w.kicad_pcb, g&w.sch]
2020-12-20 Updated Trace&Schematic with new parts numbers. Made new footprints for both BGA's and 3v3 reg. Still need to revise USB-C connector footprint.
    [g&w.kicad_pcb, g&w.sch]
2020-12-21 USB-C footprint updated from datasheet drawing 1:1 with critical dimensions layer in PCBnew
    [g&w.kicad_pcb, g&w.sch]
2020-12-22 all footprints placed, a very rough dxf graphics layer was made to locate most components, several footprints were tweaked and a few missing from the schematic were added and will be in the next revi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
    [g&w.kicad_pcb, g&w.sch]
2020-12-23 about 1/3rd routed
    [g&w.kicad_pcb, g&w.sch]
2020-12-25 first draft: full retrace of interior traces and ground plane. Also the board is designed for 3 layers, No routing conflicts found.
    [g&w.kicad_pcb, g&w.sch]
2020-12-26 Color xrays are...busy. Needs more polish, but Trace 2v0 is here.
2021-01-03 Trace 3v0
    [g&w.kicad_pcb]
2021-01-03 Trace 3.0
2021-01-04 Trace 3v1/Schematic1v2/Pinmap remade in Inkscape (SVG included in current version folder)
    [g&w.sch]
2021-01-05 Trace 3v2 and compilation pdf

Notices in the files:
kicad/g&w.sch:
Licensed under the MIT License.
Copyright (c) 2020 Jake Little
